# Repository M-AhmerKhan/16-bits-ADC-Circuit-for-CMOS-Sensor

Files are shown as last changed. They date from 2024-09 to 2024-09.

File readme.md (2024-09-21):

# Analog-Digital conversion circuit with an interface to a FPGA development board for an X-ray detector module of a 3D breast CT prototype

## Project Overview
This project focuses on the design and development of an ADC electronic circuit for a CMOS sensor coupled with CsI:Tl scintillating crystals to detects X-rays. The circuit samples analog pixels data from the sensor, crucial for analyzing beam geometry and sensor-scintillator response. An FPGA interfaces with the circuit to process the digital data from three sensor channels and store it on a host computer for image processing and analysis.
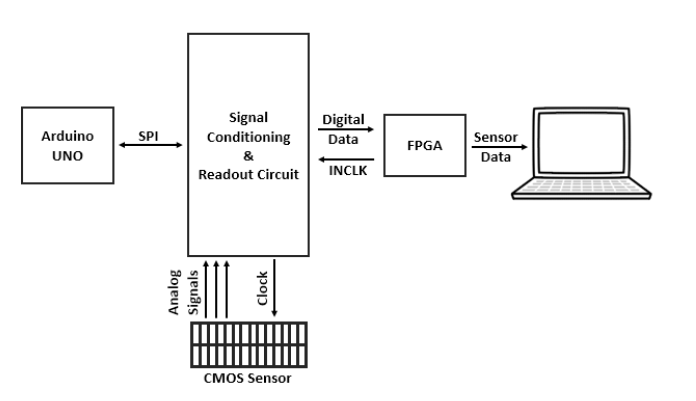
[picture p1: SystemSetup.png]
Project Overview


## Features
- 16-bits ADC circuit for 3 channel CMOS sensor.
- Serial Peripheral Interface (SPI)
- Designed voltage level shifter for interfacing +3.3V Analog front end LM98725 with a +5V CMOS sensor.
- Implemented voltage clamping circuit.
- Interfacing ADC with FPGA (NI sbRIO-9651) via LabVIEW.
- PCB layout and design using EAGLE

## Tools and Technologies

- **EAGLE** for schematic capture and PCB layout
- **LabVIEW** to acquires the digital data from the ADC in a sequence, converts this data into integer values and save the complete pixels data in a text file on the computer from each sensor channel.
- **Arduino** for SPI
- **Oscilloscope** for signal testing.
- **MATLAB** for anylyzing sesor data.

## Circuit Schematic
Here is the circuit schematic designed in EAGLE:

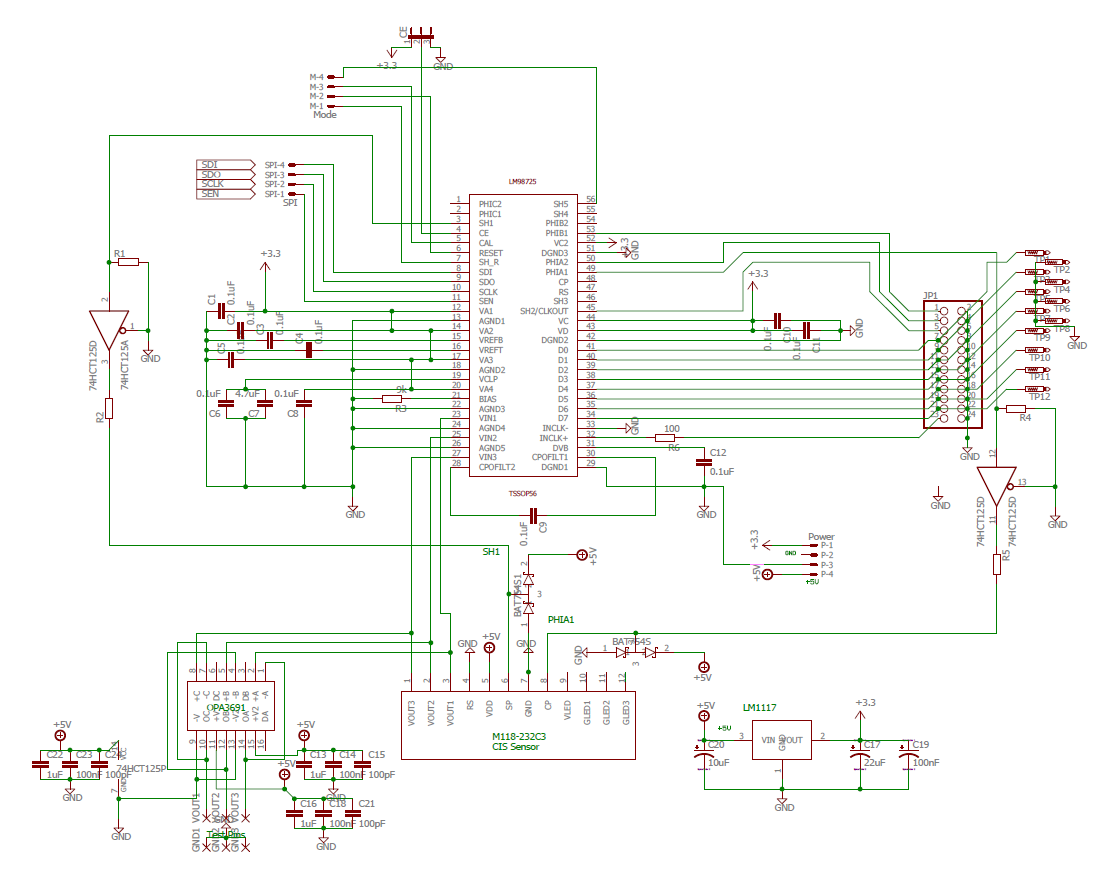
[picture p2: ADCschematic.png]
ADC Schematic


## PCB Layout
The PCB layout was created using EAGLE. Below is a preview of the PCB design:

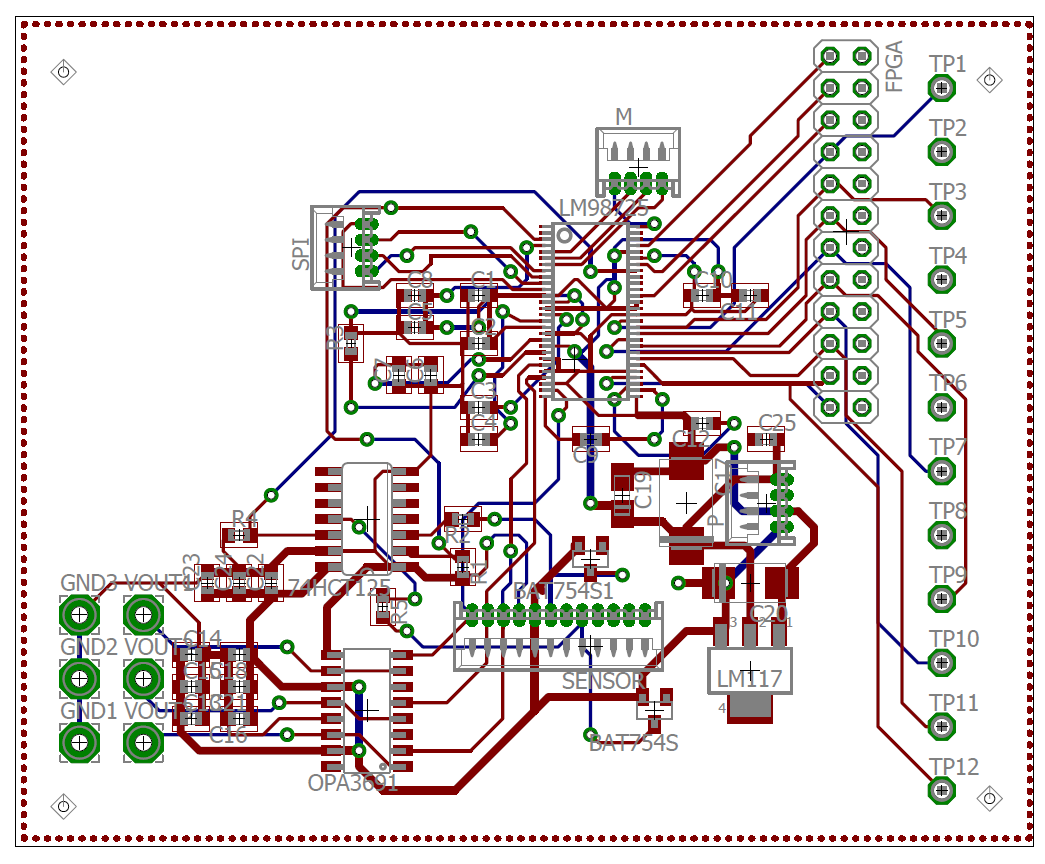
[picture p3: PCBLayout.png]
ADC PCB Layout

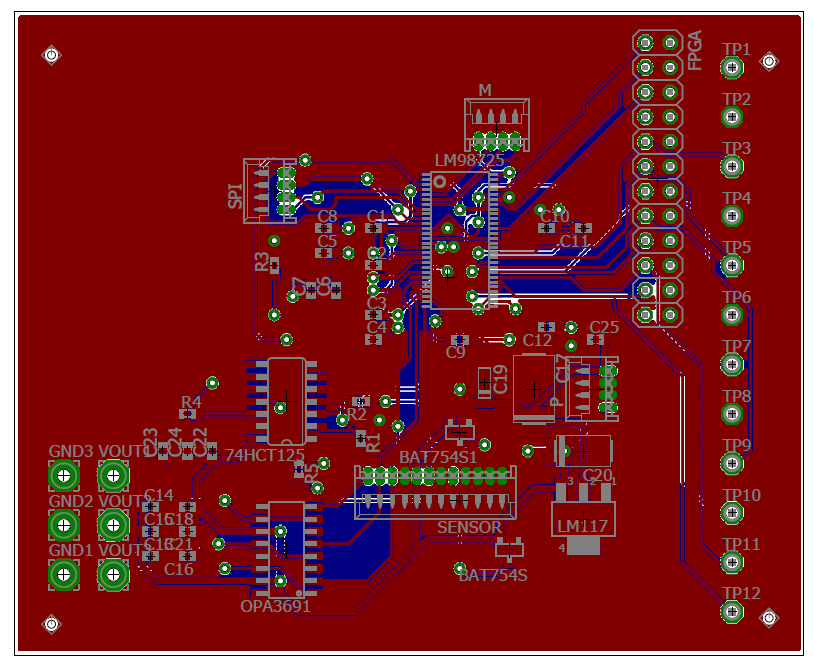
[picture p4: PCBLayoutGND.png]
ADC PCB Layout


## Designed PCB
Final designed PCB:

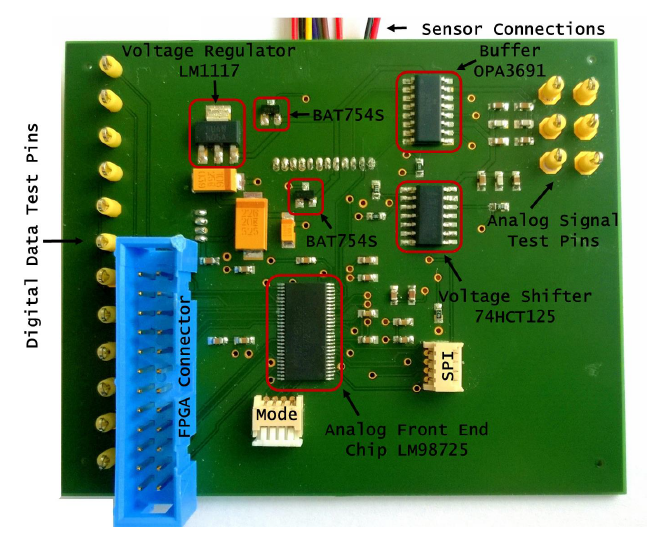
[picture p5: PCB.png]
ADC PCB


## Interfacing with FPGA

The 16 bits digital data from the ADC is arranged in a particular sequence such that it gives a single pixel value from each three channels of CMOS sensor. Two  LabVIEW programs (VI) source code are written and complied, one on the FPGA also called “target” to collects the sensor digital data and the other on the computer system referred as “host”. This data is received and saved to the host memory in the same order by implementing a FIFO method (First In First Out) that organize and prioritize the data with the time.

Communication and data flow between host computer and FPGA:
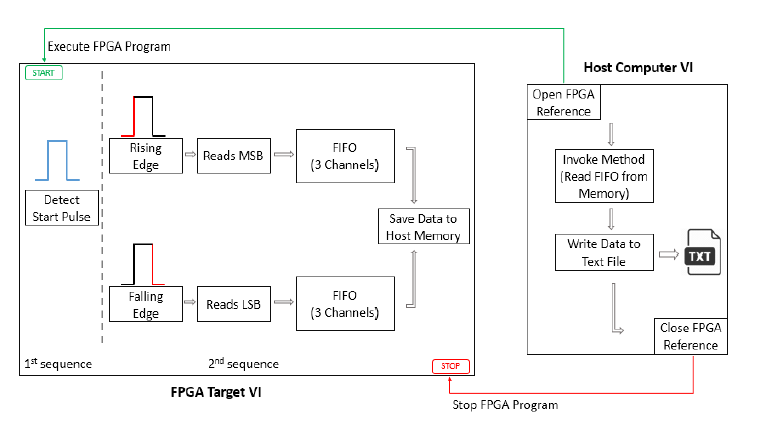
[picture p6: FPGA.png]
FPGA Interfacing


## Contact
For any questions, feel free to contact me at: [m.ahmerkhan@outlook.de](mailto:m.ahmerkhan@outlook.de).

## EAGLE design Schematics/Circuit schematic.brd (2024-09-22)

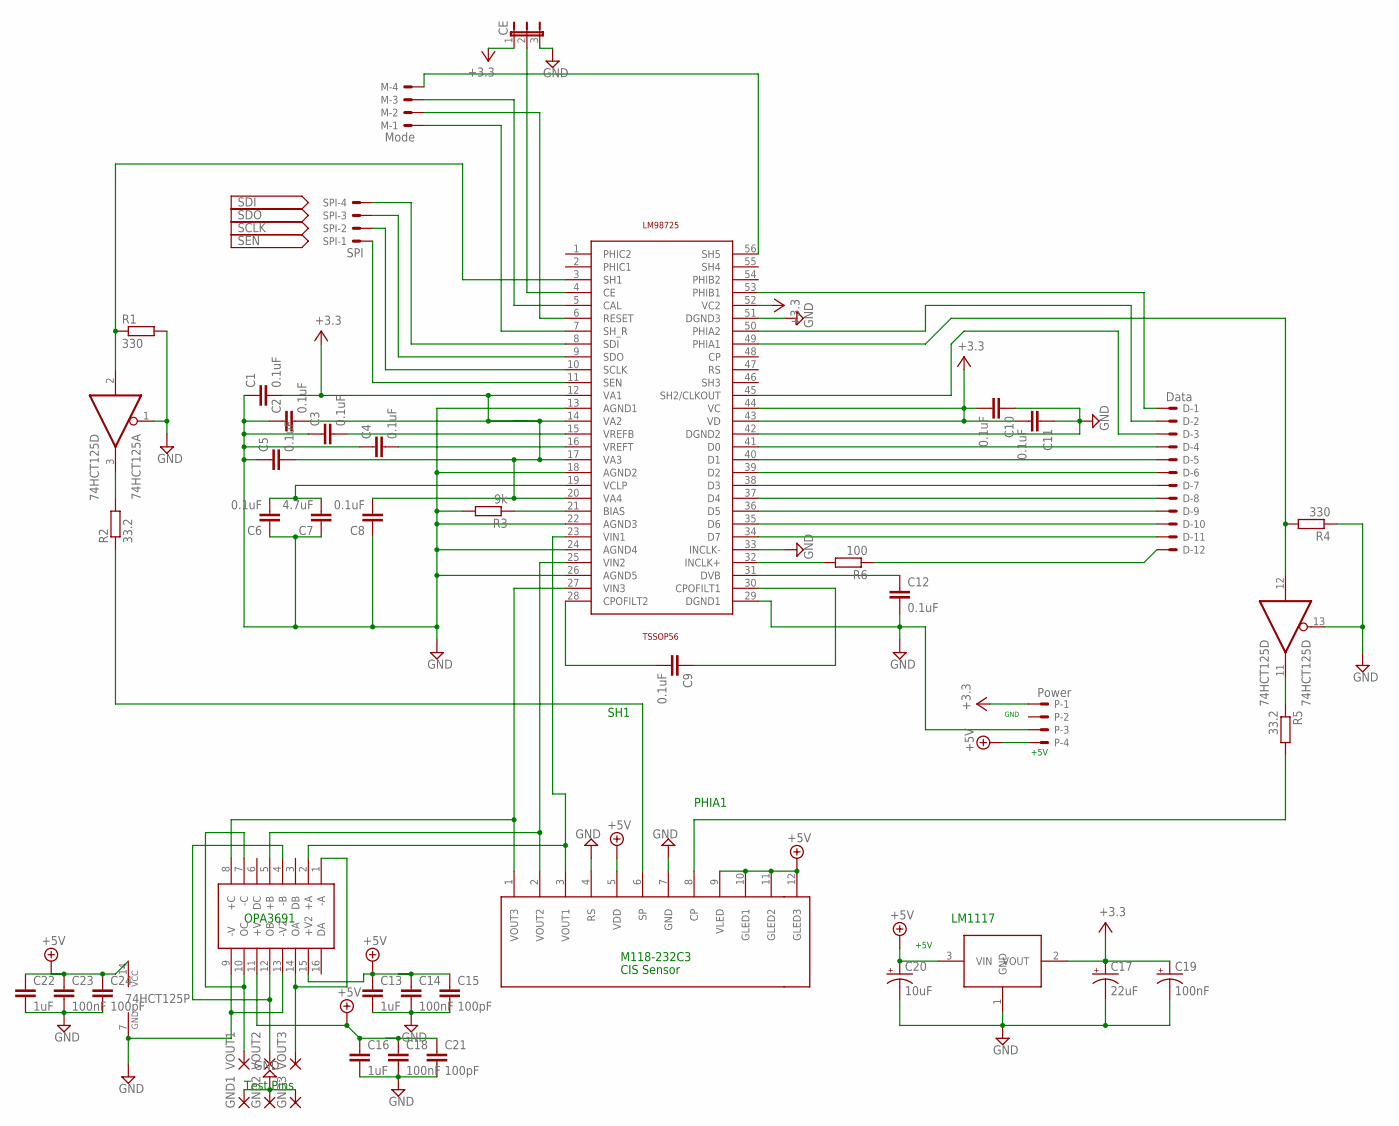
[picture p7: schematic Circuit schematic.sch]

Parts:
74HCT125: 74HCT125D; SO14
C1, C2, C3, C4, C5, C6, C8, C9, C10, C11, C12: 0.1uF; C0603
C7: 4.7uF; C0603
C13, C16, C22: 1uF; C0603
C14, C18, C23: 100nF; C0603
C15, C21, C24: 100pF; C0603
C17: 22uF; D/7343-31W
C19: 100nF; A/3216-18W
C20: 10uF; C/6032-28R
CE: JP2E; JP2
D: Data; 53048-12
GND1, GND2, GND3: 3,17/1,3
LM98725: LM98725; TSSOP56
M: Mode; 53048-04
OPA3691: OPA3691; SO16
P: Power; 53048-04
R1, R4: 330; R0603
R2, R5: 33.2; R0603
R3: 9k; R0603
R6: 100; R0603
SENSOR: CIS-M118118; 12PINPAD
SPI: SPI; 53048-04
U$2: LM117; LM
VOUT1, VOUT2, VOUT3: 3,17/1,3

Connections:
+5V: 74HCT125.14 (VCC), C13.1, C14.1, C15.1, C16.1, C18.1, C20.+, C21.1, C22.1, C23.1, C24.1, OPA3691.11 (+V), OPA3691.15 (+V2), P.4, SENSOR.5 (VDD), SENSOR.9 (VLED), SENSOR.10 (GLED1), SENSOR.11 (GLED2), SENSOR.12 (GLED3), U$2.3 (VIN)
GND: 74HCT125.1 (OE), 74HCT125.7 (GND), 74HCT125.13 (OE), C1.1, C2.1, C3.1, C4.1, C5.1, C6.1, C7.1, C8.1, C10.1, C11.1, C12.2, C13.2, C14.2, C15.2, C16.2, C17.-, C18.2, C19.-, C20.-, C21.2, C22.2, C23.2, C24.2, CE.3, GND1.1, GND2.1, GND3.1, LM98725.13 (AGND1), LM98725.18 (AGND2), LM98725.22 (AGND3), LM98725.24 (AGND4), LM98725.26 (AGND5), LM98725.29 (DGND1), LM98725.33 (INCLK-), LM98725.42 (DGND2), LM98725.51 (DGND3), OPA3691.9 (-V), OPA3691.13 (-V2), P.3, R1.2, R3.2, R4.1, SENSOR.4 (RS), SENSOR.7 (GND), U$2.1 (GND)
unnamed: C9.2, LM98725.28 (CPOFILT2)
unnamed: C9.1, LM98725.30 (CPOFILT1)
unnamed: OPA3691.4 (-B), OPA3691.12 (OB), VOUT2.1
unnamed: C12.1, LM98725.31 (DVB)
unnamed: OPA3691.1 (-A), OPA3691.14 (OA), VOUT3.1
unnamed: OPA3691.7 (-C), OPA3691.10 (OC), VOUT1.1
unnamed: LM98725.25 (VIN2), OPA3691.5 (+B), SENSOR.2 (VOUT2)
unnamed: CE.2, LM98725.4 (CE)
unnamed: LM98725.32 (INCLK+), R6.2
unnamed: C4.2, LM98725.16 (VREFT)
unnamed: LM98725.8 (SDI), SPI.4
unnamed: LM98725.21 (BIAS), R3.1
unnamed: C6.2, C7.2, LM98725.19 (VCLP)
unnamed: LM98725.9 (SDO), SPI.3
unnamed: LM98725.10 (SCLK), SPI.2
unnamed: LM98725.5 (CAL), M.3
unnamed: LM98725.11 (SEN), SPI.1
unnamed: LM98725.6 (RESET), M.2
unnamed: LM98725.7 (SH_R), M.1
unnamed: D.12, R6.1
unnamed: D.11, LM98725.34 (D7)
unnamed: D.3, LM98725.45 (SH2/CLKOUT)
unnamed: LM98725.56 (SH5), M.4
unnamed: D.1, LM98725.53 (PHIB1)
unnamed: D.2, LM98725.50 (PHIA2)
unnamed: D.10, LM98725.35 (D6)
unnamed: D.9, LM98725.36 (D5)
unnamed: D.8, LM98725.37 (D4)
unnamed: D.6, LM98725.39 (D2)
unnamed: D.7, LM98725.38 (D3)
unnamed: D.5, LM98725.40 (D1)
unnamed: D.4, LM98725.41 (D0)
unnamed: 74HCT125.3 (O), R2.2
unnamed: R5.2, SENSOR.8 (CP)
unnamed: LM98725.23 (VIN1), OPA3691.2 (+A), SENSOR.3 (VOUT1)
unnamed: R2.1, SENSOR.6 (SP)
unnamed: 74HCT125.2 (I), LM98725.3 (SH1), R1.1
unnamed: C3.2, LM98725.15 (VREFB)
unnamed: 74HCT125.12 (I), LM98725.49 (PHIA1), R4.2
unnamed: 74HCT125.11 (O), R5.1
unnamed: LM98725.27 (VIN3), OPA3691.8 (+C), SENSOR.1 (VOUT3)
V+: C1.2, C2.2, C5.2, C8.2, C10.2, C11.2, C17.+, C19.+, CE.1, LM98725.12 (VA1), LM98725.14 (VA2), LM98725.17 (VA3), LM98725.20 (VA4), LM98725.43 (VD), LM98725.44 (VC), LM98725.52 (VC2), P.1, U$2.2 (VOUT)

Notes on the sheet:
+5V
GND
LM1117
Test Pins
PHIA1
SH1
M118-232C3
CIS Sensor
OPA3691

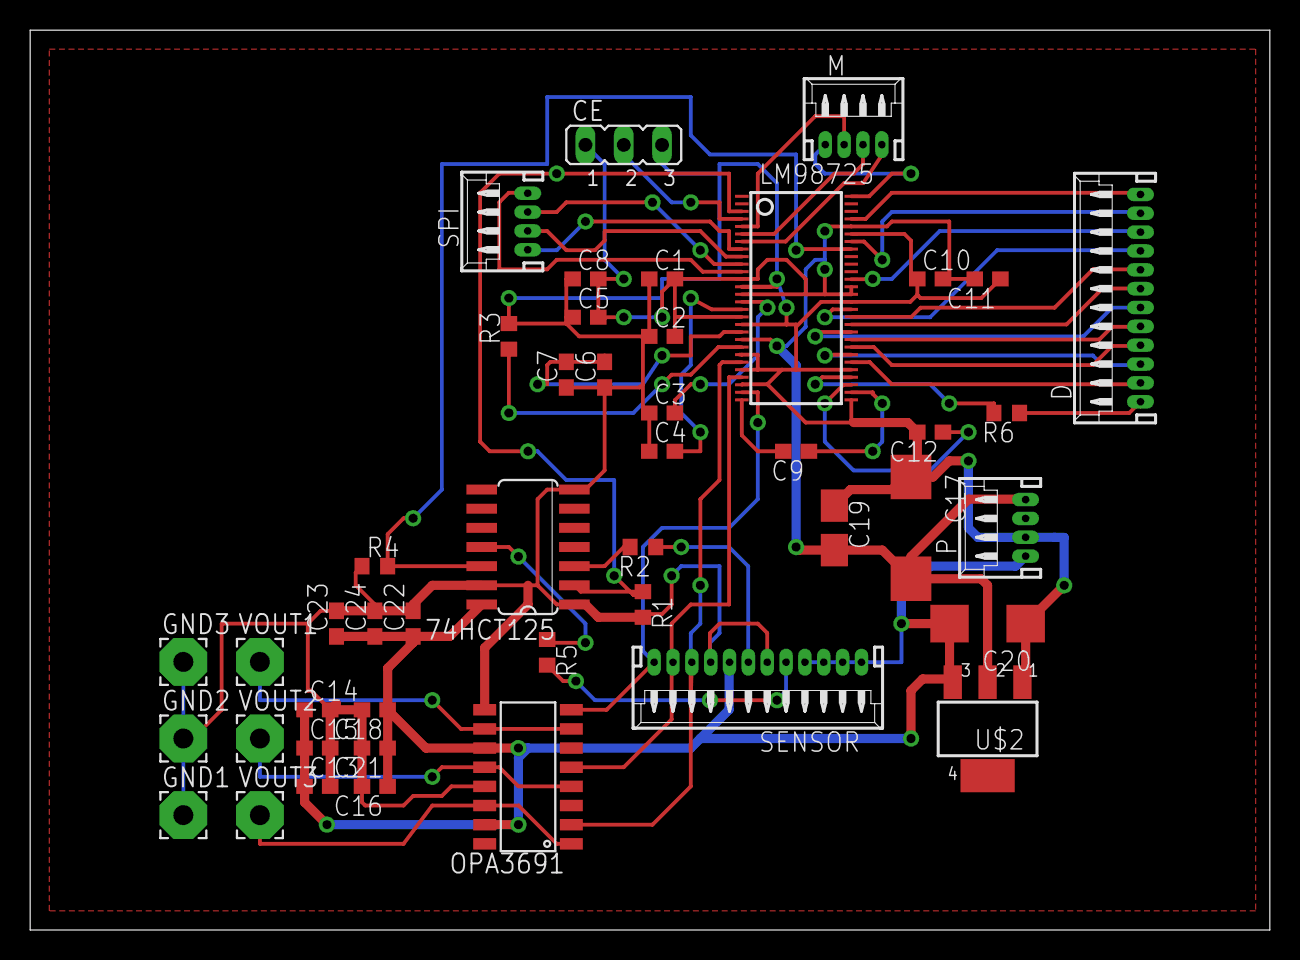
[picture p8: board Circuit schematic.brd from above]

Board: 2 copper layers, 82.2 x 59.7 mm, 46 parts (0 on the bottom side), 44 nets.

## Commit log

2024-09-21 Rename ADC schematic.png to ADCschematic.png
2024-09-21 Rename PCB Layout (1).png to PCBLayoutGND.png
2024-09-21 Rename PCB Layout (2).png to PCBLayout.png
2024-09-22 Create Schematics
